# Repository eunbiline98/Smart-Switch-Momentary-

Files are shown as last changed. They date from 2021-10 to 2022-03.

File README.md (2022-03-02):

# Smart Switch Momentary

DIY Smart Switch momentary 2 Gang and 2 Channel Relay SPDT

List Item

- Esp8266 (Wemos D1 Mini) / Chip SoC Esp8266
- Relay 5VDC SPDT Songle (Max Current 10A)
- Power Module Hi-Link 220VAC to 5VDC
- Resistor 1k, 10K (SMD 0805)
- Diode 1N4007 SMD
- Transistor 2n2222a
- Terminal Screw 6 Pin Hole
- Push Button (schneider momentary switch) Datasheet: https://download.schneider-electric.com/files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

# Schematic
schematic

# Layout 
### Top View 
top

### Bottom View
bottom

# Home Assistant

Under covers in HA, use this config

```
mqtt:
  broker: "Your IP Broker/server"
  port: Your port MQTT
  username: "Your username"
  password: Your password

switch:
  - platform: mqtt
    name: "General Lamp"
    state_topic: "switch/bedroom1/1/state"
    command_topic: "switch/1/command"
    payload_on: "1"
    payload_off: "0"

 switch:
  - platform: mqtt
    name: "Cove Lighting"
    state_topic: "switch/bedroom1/2/state"
    command_topic: "switch/2/command"
    payload_on: "1"
    payload_off: "0"
```



IMAGE ALT TEXT HERE (https://www.youtube.com/watch?v=DARuhkKLw8E")

# Reference

- WiFi Manager (https://github.com/tzapu/WiFiManager)
- MQTT (https://github.com/knolleary/pubsubclient)

# Update

- DIY_switch_3_gang_Ver_1_0 (Test Board Circuit)
- DIY_switch_3_gang_Ver_1_0_WM (Update Feature WifI Manager)
- DIY_switch_3_gang_Ver_1_1_WM (Update Last State Condition Dashboard Home Assistant)
- DIY_switch_3_gang_Ver_1_2_WM (Update Feature WiFi and Mqtt Config Manager)

# Dimension

- L = 69,84 mm
- W = 70,87 mm

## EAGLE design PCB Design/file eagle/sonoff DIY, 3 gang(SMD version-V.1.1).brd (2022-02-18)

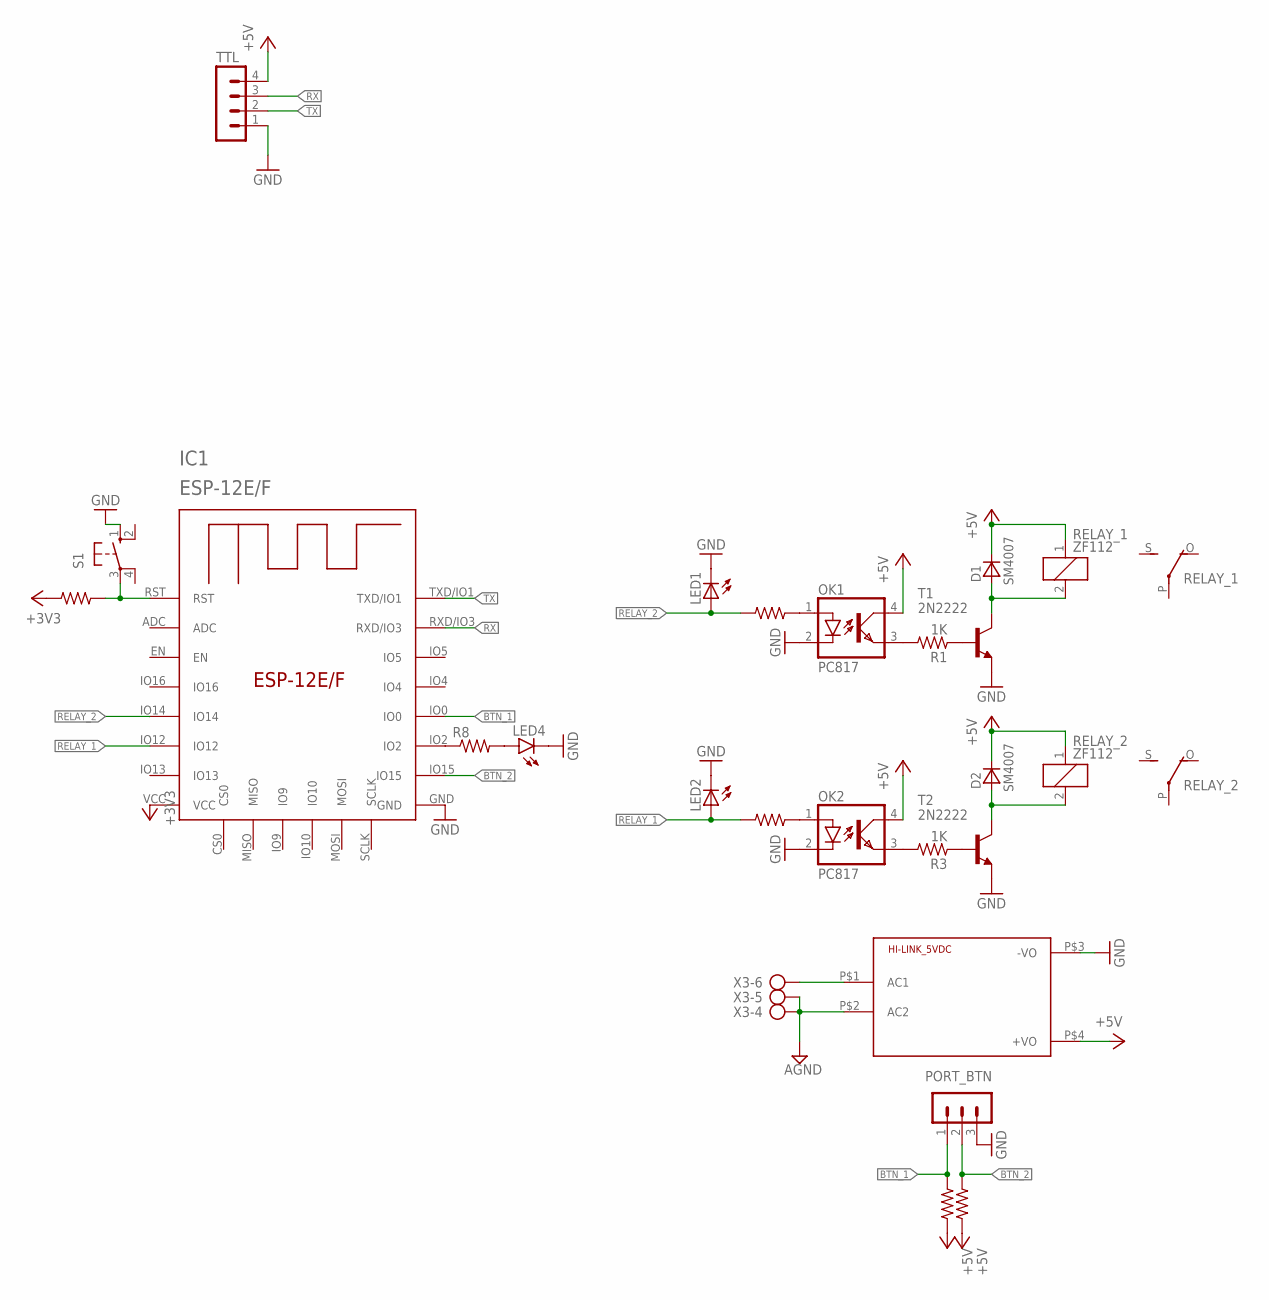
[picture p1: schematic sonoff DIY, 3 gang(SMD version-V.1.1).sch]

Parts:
D1, D2: SM4007; MELF-MLL41
HI-LINK_5VDC: HLK-PM013W; HLK-PM01
IC1: ESP-12E/F; ESP-12E
LED1, LED2, LED4: LED3MM
OK1, OK2: PC817; DIL04
PORT_BTN: MA03-1
R1, R2, R3, R4, R5, R6, R7: 1K; R0805
R8: R-US_0207/10; 0207/10
RELAY_1, RELAY_2: ZF112
S1: 10-XX; B3F-10XX
T1, T2: 2N2222; TO18
TTL: MA04-1
X3: SMKDSP_1,5/6

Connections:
+3V3: IC1.VCC, R7.2
+5V: D1.C, D2.C, HI-LINK_5VDC.P$4 (+VO), OK1.4 (COL), OK2.4 (COL), R5.2, R6.2, RELAY_1.1, RELAY_2.1, TTL.4
AGND: HI-LINK_5VDC.P$2 (AC2), X3.4, X3.5
BTN_1: IC1.IO0, PORT_BTN.1, R5.1
BTN_2: IC1.IO15, PORT_BTN.2, R6.1
GND: HI-LINK_5VDC.P$3 (-VO), IC1.GND, LED1.K (C), LED2.K (C), LED4.K (C), OK1.2 (C), OK2.2 (C), PORT_BTN.3, S1.1 (S), T1.1 (E), T2.1 (E), TTL.1
unnamed: OK1.1 (A), R2.1
unnamed: OK1.3 (EMIT), R1.2
unnamed: R1.1, T1.2 (B)
unnamed: D1.A, RELAY_1.2, T1.3 (C)
unnamed: OK2.1 (A), R4.1
unnamed: HI-LINK_5VDC.P$1 (AC1), X3.6
unnamed: OK2.3 (EMIT), R3.2
unnamed: R3.1, T2.2 (B)
unnamed: D2.A, RELAY_2.2, T2.3 (C)
unnamed: IC1.RST, R7.1, S1.3
unnamed: IC1.IO2, R8.1
unnamed: LED4.A, R8.2
RELAY_1: IC1.IO12, LED2.A, R4.2
RELAY_2: IC1.IO14, LED1.A, R2.2
RX: IC1.RXD/IO3, TTL.3
TX: IC1.TXD/IO1, TTL.2

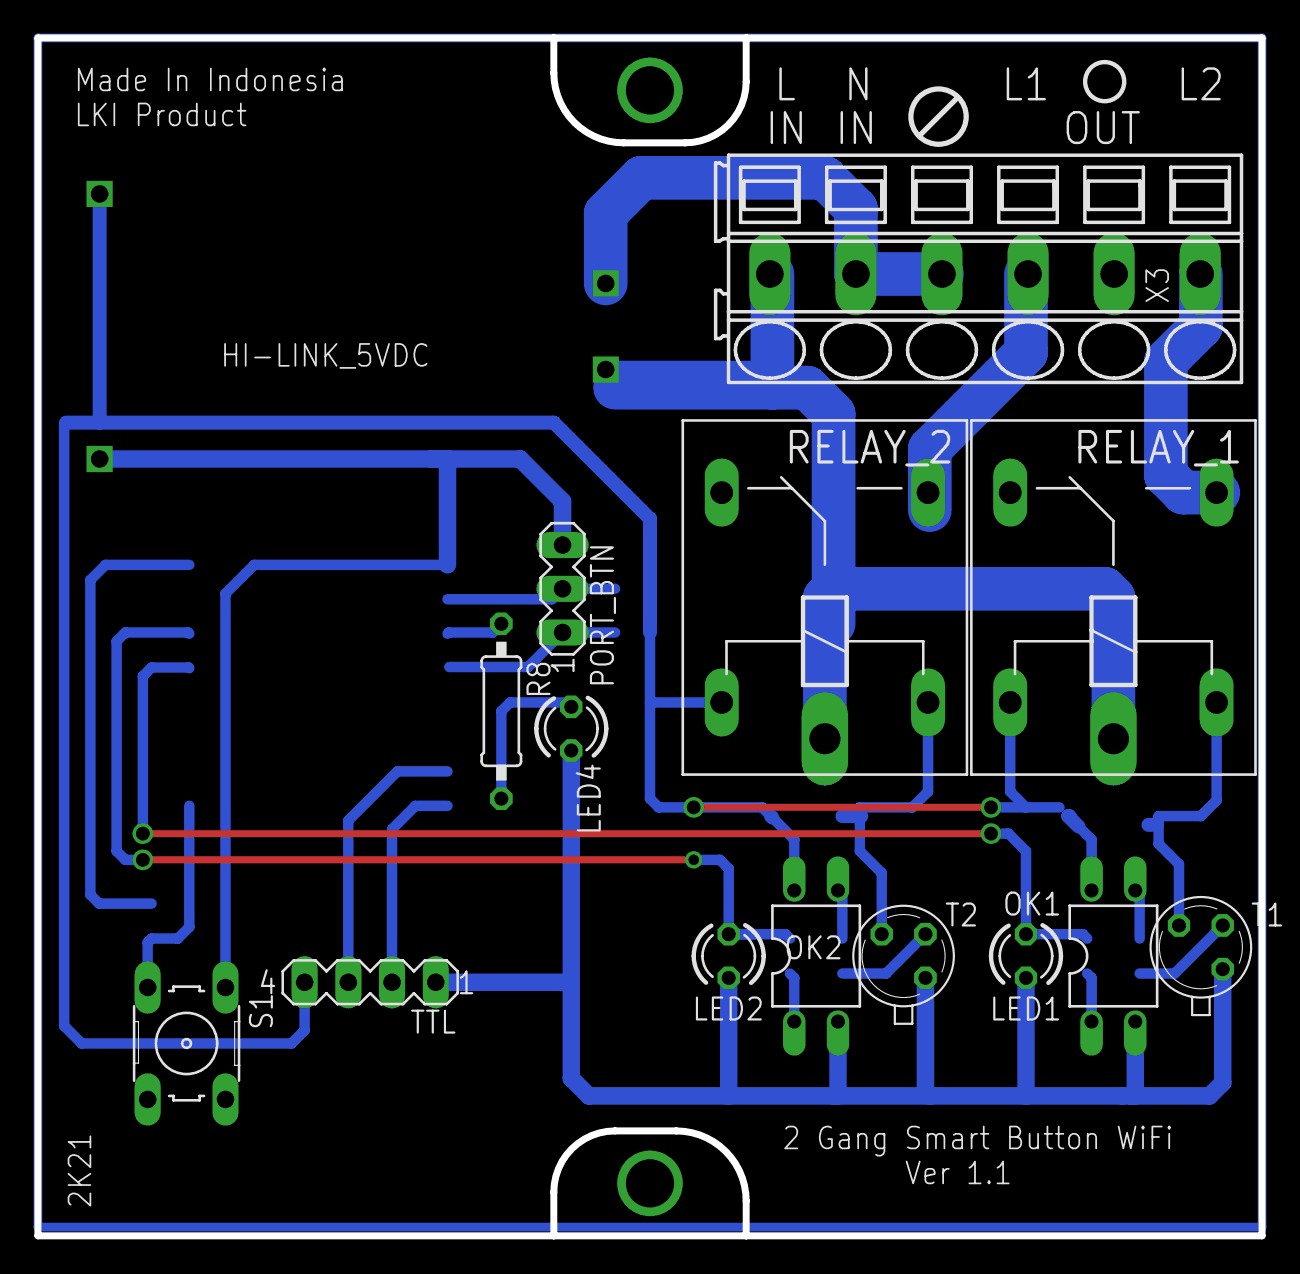
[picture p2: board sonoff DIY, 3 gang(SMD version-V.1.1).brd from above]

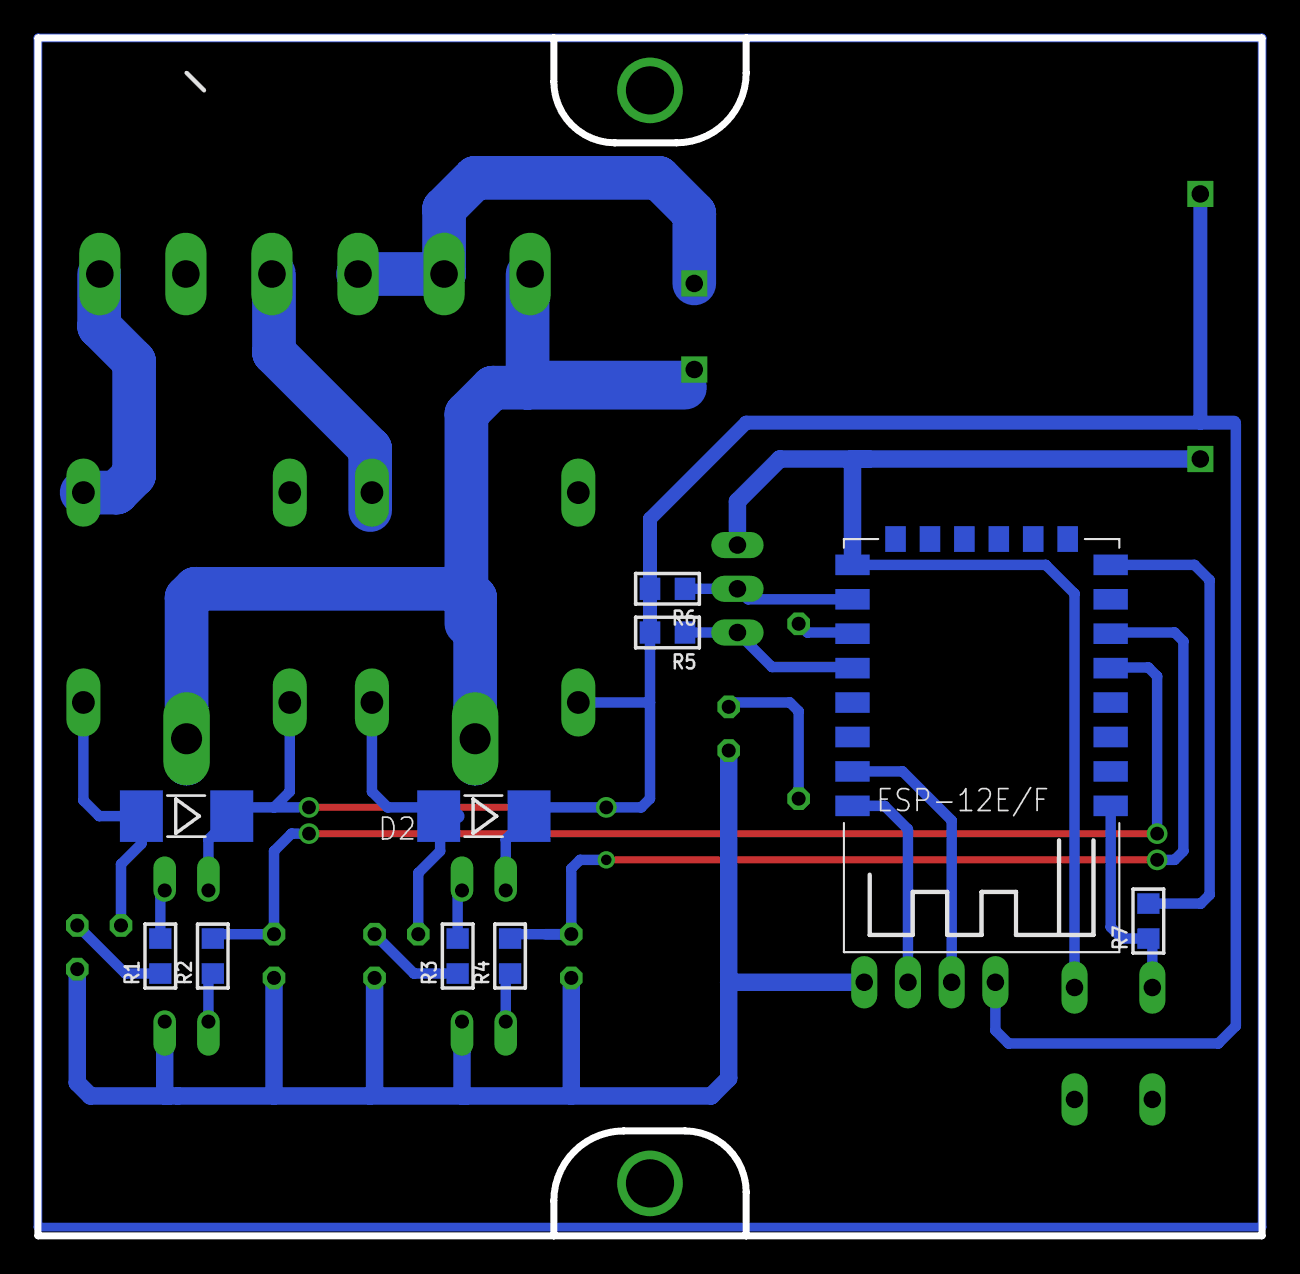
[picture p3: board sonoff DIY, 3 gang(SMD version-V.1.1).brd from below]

Board: 2 copper layers, 71.1 x 69.6 mm, 25 parts (10 on the bottom side), 22 nets.

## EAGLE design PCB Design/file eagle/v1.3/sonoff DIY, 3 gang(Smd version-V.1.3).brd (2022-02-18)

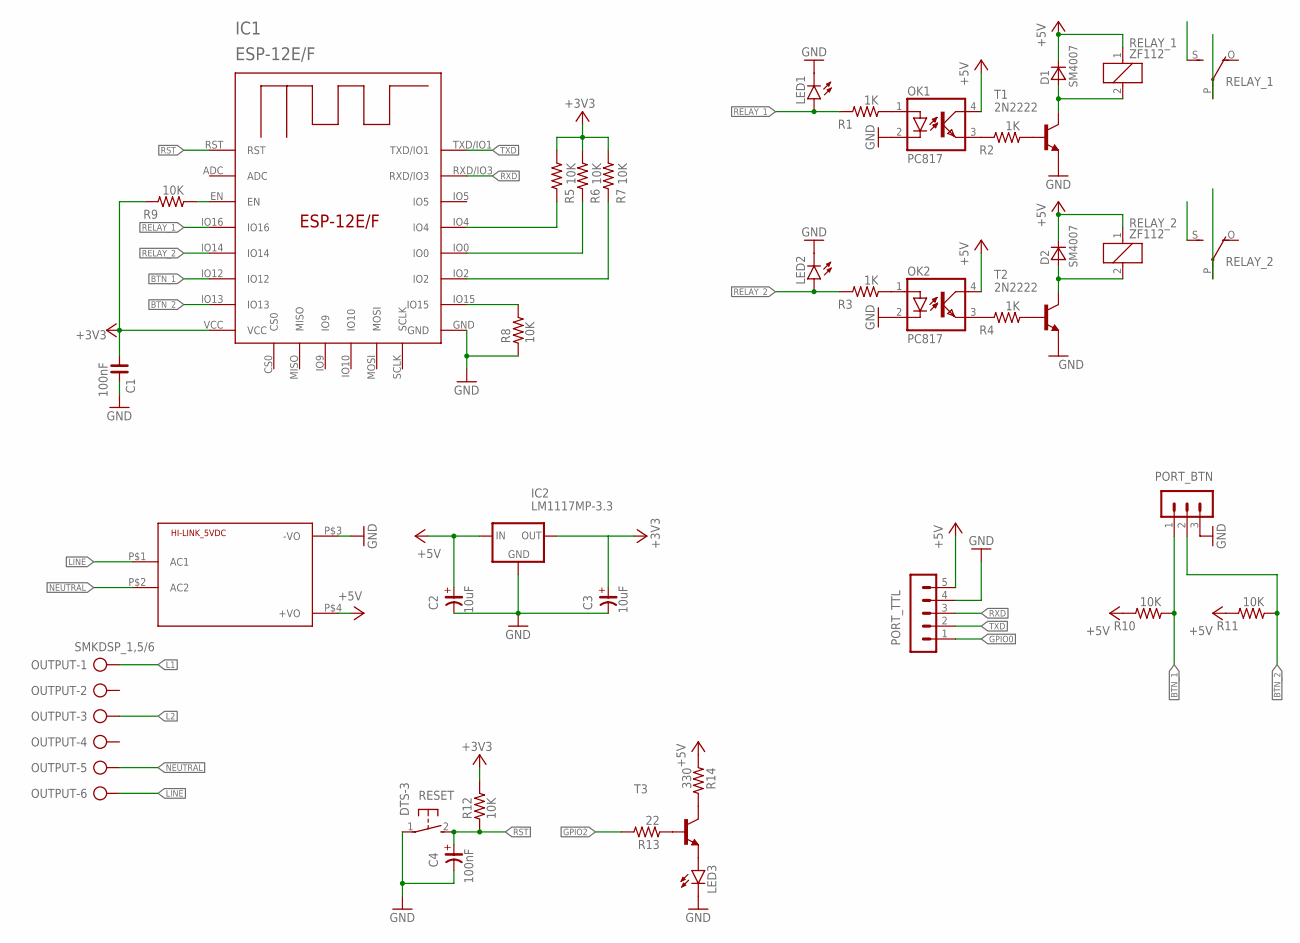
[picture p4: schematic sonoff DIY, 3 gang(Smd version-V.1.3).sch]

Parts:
C1: 100nF; C0805
C2, C3: 10uF; C3528/T
C4: 100nF; C3528/T
D1, D2: SM4007; MELF-MLL41
HI-LINK_5VDC: HLK-PM013W; HLK-PM01
IC1: ESP-12E/F; ESP-12E
IC2: LM1117MP-3.3; SOT223
LED1, LED2, LED3: LED3MM
OK1, OK2: PC817; DIL04
OUTPUT: SMKDSP_1,5/6
PORT_BTN: MA03-1
PORT_TTL: MA05-1
R1, R2, R3, R4: 1K; R0805
R5, R6, R7, R8, R9, R10, R11, R12: 10K; R0805
R13: 22; R0805
R14: 330; R0805
RELAY_1, RELAY_2: ZF112
RESET: DTS-3
T1, T2: 2N2222; TO18
T3: BC817-16LT1-NPN-SOT23-BEC; SOT23-BEC

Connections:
+3V3: C1.1, C3.+, IC1.VCC, IC2.2 (OUT), IC2.4 (OUT), R5.1, R6.1, R7.1, R9.2, R12.2
+5V: C2.+, D1.C, D2.C, HI-LINK_5VDC.P$4 (+VO), IC2.3 (IN), OK1.4 (COL), OK2.4 (COL), PORT_TTL.5, R10.2, R11.2, R14.1, RELAY_1.1, RELAY_2.1
BTN_1: IC1.IO12, PORT_BTN.1, R10.1
BTN_2: IC1.IO13, PORT_BTN.2, R11.1
GND: C1.2, C2.-, C3.-, C4.-, HI-LINK_5VDC.P$3 (-VO), IC1.GND, IC2.1 (GND), LED1.K (C), LED2.K (C), LED3.K (C), OK1.2 (C), OK2.2 (C), PORT_BTN.3, PORT_TTL.4, R8.1, RESET.1, T1.1 (E), T2.1 (E)
GPIO0: IC1.IO0, PORT_TTL.1, R6.2
GPIO2: IC1.IO2, R7.2, R13.2
L1: OUTPUT.1, RELAY_1.S
L2: OUTPUT.3, RELAY_2.S
LINE: HI-LINK_5VDC.P$1 (AC1), OUTPUT.6, RELAY_1.P, RELAY_2.P
unnamed: OK1.3 (EMIT), R2.2
unnamed: R2.1, T1.2 (B)
unnamed: OK2.1 (A), R3.1
unnamed: D1.A, RELAY_1.2, T1.3 (C)
unnamed: OK2.3 (EMIT), R4.2
unnamed: R4.1, T2.2 (B)
unnamed: OK1.1 (A), R1.1
unnamed: IC1.IO4, R5.2
unnamed: D2.A, RELAY_2.2, T2.3 (C)
unnamed: LED3.A, T3.E
unnamed: IC1.IO15, R8.2
unnamed: R13.1, T3.B
unnamed: IC1.EN, R9.1
unnamed: R14.2, T3.C
NEUTRAL: HI-LINK_5VDC.P$2 (AC2), OUTPUT.5
RELAY_1: IC1.IO16, LED1.A, R1.2
RELAY_2: IC1.IO14, LED2.A, R3.2
RST: C4.+, IC1.RST, R12.1, RESET.2
RXD: IC1.RXD/IO3, PORT_TTL.3
TXD: IC1.TXD/IO1, PORT_TTL.2

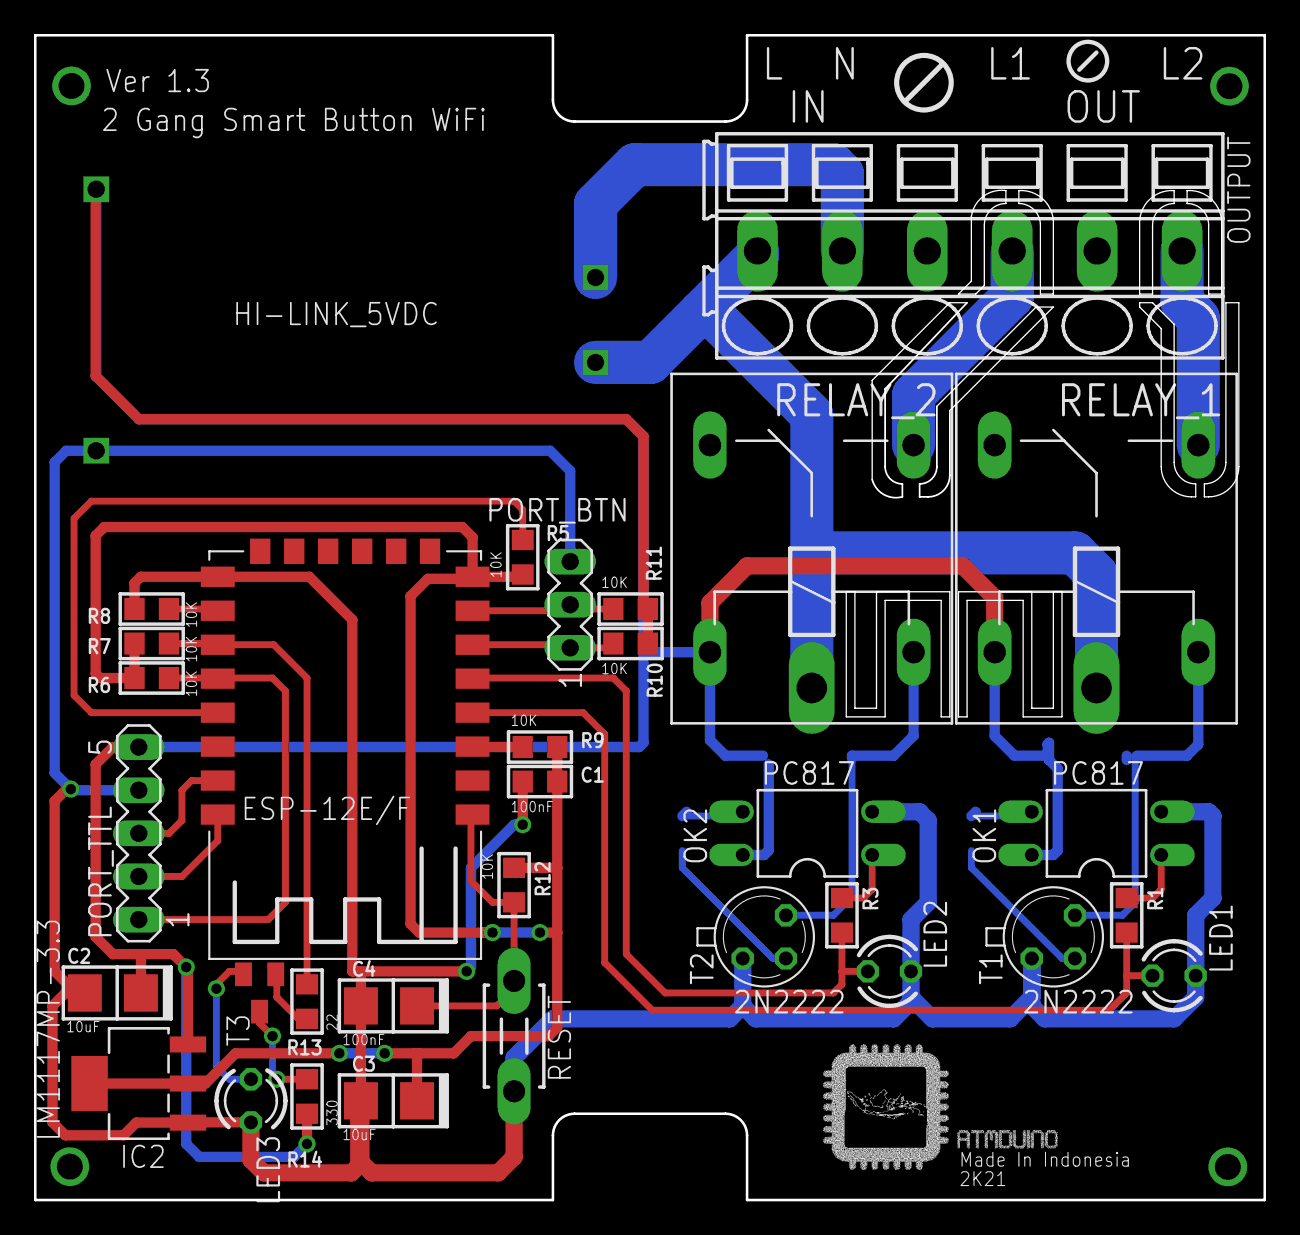
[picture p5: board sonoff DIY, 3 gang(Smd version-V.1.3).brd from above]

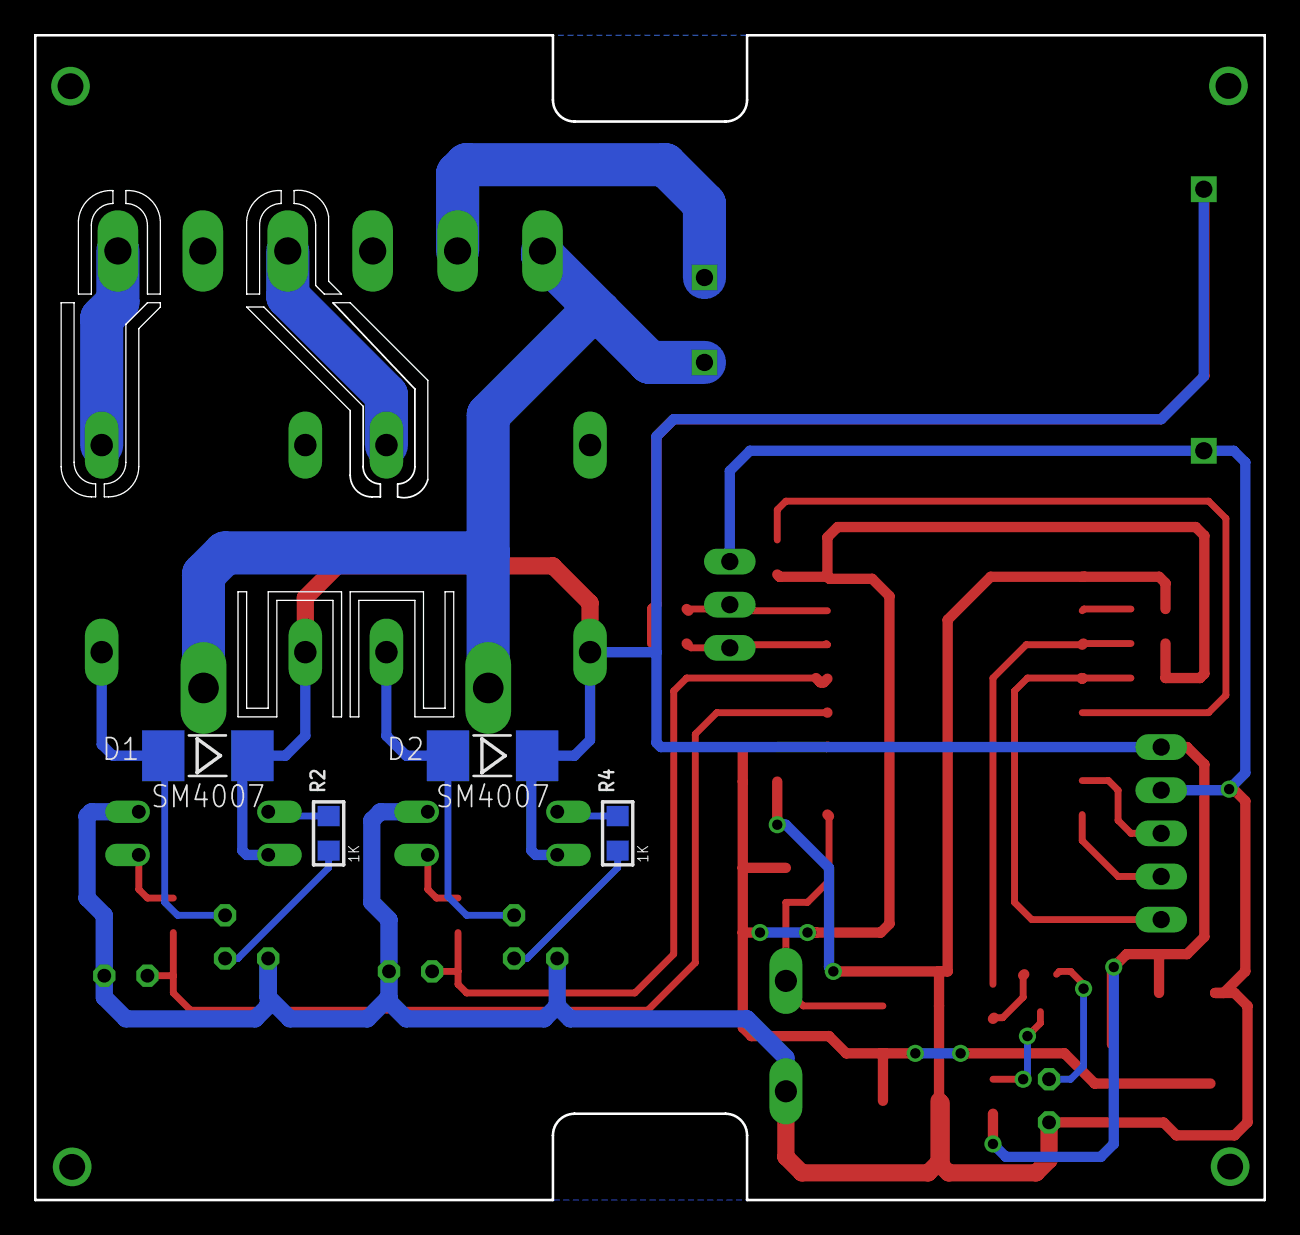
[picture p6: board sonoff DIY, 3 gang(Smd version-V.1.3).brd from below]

Board: 2 copper layers, 72.4 x 68.6 mm, 37 parts (4 on the bottom side), 30 nets.

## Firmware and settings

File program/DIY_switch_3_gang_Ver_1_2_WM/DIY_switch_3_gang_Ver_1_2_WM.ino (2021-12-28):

#include <ESP8266WiFi.h>
#include <PubSubClient.h>
#include <WiFiManager.h>
#include <Ticker.h>
#include <FS.h>
#include <ArduinoJson.h>
#include <DNSServer.h>

// set at text box mqtt config manager
#define MQTT_SERVER "Input Your Broker"
#define MQTT_PORT "Input Your Port"
#define MQTT_USERNAME "Input Your Username"
#define MQTT_PASSWORD "Input Your Password"

const char *MQTT_TOPIC1 = "switch/bedroom1/1/state";
const char *MQTT_TOPIC2 = "switch/bedroom1/2/state";
const char *MQTT_STATUS = "switch/bedroom1/status";
const char *SWITCH1 = "switch/1/command";
const char *SWITCH2 = "switch/2/command";

const char *MQTT_CLIENT_ID = "swtich_ID_1";

// Pin Setup
#define relay_1 14
#define relay_2 12
#define btn_1 5
#define btn_2 4

int flag1 = 0;
int flag2 = 0;
int state = 0;
int wifi_trigger = 0;

int lastMilis = 0;
unsigned long nowMillis = millis();
bool shouldSaveConfig = false;

WiFiClient espClient;
PubSubClient client(espClient);
Ticker ticker;

// callback notifying us of the need to save config
void saveConfigCallback()
{
  Serial.println("Should save config");
  shouldSaveConfig = true;
}

void tick()
{
  // toggle state
  digitalWrite(2, !digitalRead(2)); // set pin GPIO2 Led Wemos On-board
}

void configModeCallback(WiFiManager *myWiFiManager)
{
  Serial.println("Entered config mode");
  Serial.println(WiFi.softAPIP());
  // if you used auto generated SSID, print it
  Serial.println(myWiFiManager->getConfigPortalSSID());
  // entered config mode, make led toggle faster
  ticker.attach(0.2, tick);
}

void setup_wifi()
{
  WiFi.mode(WIFI_STA);
  pinMode(2, OUTPUT);
  ticker.attach(0.6, tick);

  // clean FS for testing
  //   SPIFFS.format();

  // read configuration from FS json
  Serial.println("mounting FS...");

  if (SPIFFS.begin())
  {
    Serial.println("mounted file system");
    if (SPIFFS.exists("/config.json"))
    {
      // file exists, reading and loading
      Serial.println("reading config file");
      File configFile = SPIFFS.open("/config.json", "r");
      if (configFile)
      {
        Serial.println("opened config file");
        size_t size = configFile.size();
        // Allocate a buffer to store contents of the file.
        std::unique_ptr<char[]> buf(new char[size]);

        configFile.readBytes(buf.get(), size);
        DynamicJsonBuffer jsonBuffer;
        JsonObject &json = jsonBuffer.parseObject(buf.get());
        json.printTo(Serial);
        if (json.success())
        {
          Serial.println("\nparsed json");
          strcpy(MQTT_SERVER, json["mqtt_server"]);
          strcpy(MQTT_PORT, json["mqtt_port"]);
          strcpy(MQTT_USERNAME, json["mqtt_username"]);
          strcpy(MQTT_PASSWORD, json["mqtt_password"]);
        }
        else
        {

          Serial.println("failed to load json config");
        }
      }
    }
  }
  else
  {
    Serial.println("failed to mount FS");
  }

  WiFiManagerParameter custom_mqtt_server("server", "mqtt server", MQTT_SERVER, 40);
  WiFiManagerParameter custom_mqtt_port("port", "mqtt port", MQTT_PORT, 40);
  WiFiManagerParameter custom_mqtt_user("user", "mqtt user", MQTT_USERNAME, 40);
  WiFiManagerParameter custom_mqtt_pass("pass", "mqtt pass", MQTT_PASSWORD, 40);

  WiFiManager wm;
  wm.setAPCallback(configModeCallback);

  wm.addParameter(&custom_mqtt_server);
  wm.addParameter(&custom_mqtt_port);
  wm.addParameter(&custom_mqtt_user);
  wm.addParameter(&custom_mqtt_pass);

  if (!wm.autoConnect() || digitalRead(btn_2) == LOW)
  {
    Serial.println("failed to connect");
    wm.resetSettings();
    ESP.restart();
    delay(1000);
  }

  Serial.println("connected...");

  strcpy(MQTT_SERVER, custom_mqtt_server.getValue());
  strcpy(MQTT_PORT, custom_mqtt_port.getValue());
  strcpy(MQTT_USERNAME, custom_mqtt_user.getValue());
  strcpy(MQTT_PASSWORD, custom_mqtt_pass.getValue());

  // save the custom parameters to FS
  if (shouldSaveConfig)
  {
    Serial.println("saving config");
    DynamicJsonBuffer jsonBuffer;
    JsonObject &json = jsonBuffer.createObject();
    json["mqtt_server"] = MQTT_SERVER;
    json["mqtt_port"] = MQTT_PORT;
    json["mqtt_user"] = MQTT_USERNAME;
    json["mqtt_pass"] = MQTT_PASSWORD;

    File configFile = SPIFFS.open("/config.json", "w");
    if (!configFile)
    {
      Serial.println("failed to open config file for writing");
    }

    json.printTo(Serial);
    json.printTo(configFile);
    configFile.close();
    // end save
  }

  ticker.detach();
  digitalWrite(2, LOW);
}

void button_func()
{
  // button1
  int stateBtn_1 = digitalRead(btn_1);
  if (!stateBtn_1 && !flag1)
  {
    if (state == 0)
    {
      client.publish(MQTT_TOPIC1, "1");
      digitalWrite(relay_1, HIGH);
      state = 1;
    }
    else
    {
      client.publish(MQTT_TOPIC1, "0");
      digitalWrite(relay_1, LOW);
      state = 0;
    }
    flag1 = 1;
  }
  else if (stateBtn_1 && flag1)
  {
    flag1 = 0;
  }
  // button2
  int stateBtn_2 = digitalRead(btn_2);
  if (!stateBtn_2 && !flag2)
  {
    if (state == 0)
    {
      client.publish(MQTT_TOPIC2, "1");
      digitalWrite(relay_2, HIGH);
      state = 1;
    }
    else
    {
      client.publish(MQTT_TOPIC2, "0");
      digitalWrite(relay_2, LOW);
      state = 0;
    }
    flag2 = 1;
  }
  else if (stateBtn_2 && flag2)
  {
    flag2 = 0;
  }
  delay(100);
}

void callback(char *topic, byte *message, unsigned int length)
{
  Serial.print("Message arrived in topic: ");
  Serial.println(topic);
  Serial.print("Message:");
  String messageTemp;

  for (int i = 0; i < length; i++)
  {
    Serial.print((char)message[i]);
    Serial.println();
    if ((char)message[i] != '"')
      messageTemp += (char)message[i];
  }

  if (String(topic) == SWITCH1)
  {
    if (messageTemp == "1")
    {
      digitalWrite(relay_1, HIGH);
      client.publish(MQTT_TOPIC1, "1");
    }
    else if (messageTemp == "0")
    {
      digitalWrite(relay_1, LOW);
      client.publish(MQTT_TOPIC1, "0");
    }
  }

  if (String(topic) == SWITCH2)
  {
    if (messageTemp == "1")
    {
      digitalWrite(relay_2, HIGH);
      client.publish(MQTT_TOPIC2, "1");
    }
    else if (messageTemp == "0")
    {
      digitalWrite(relay_2, LOW);
      client.publish(MQTT_TOPIC2, "0");
    }
  }
}

void reconnect()
{
  // Loop until we're reconnected
  while (!client.connected())
  {
    Serial.print("Attempting MQTT connection...");
    // Attempt to connect
    if (client.connect(MQTT_CLIENT_ID, MQTT_USERNAME, MQTT_PASSWORD, MQTT_STATUS, 1, 1, "Offline"))
    {
      Serial.println("connected");
      // subscribe
      client.subscribe(SWITCH1);
      client.subscribe(SWITCH2);
      client.publish(MQTT_STATUS, "Online", true);
    }
    else
    {
      Serial.print("failed, rc=");
      Serial.print(client.state());
      Serial.println(" try again in 5 seconds");
      // Wait 5 seconds before retrying
      delay(5000);
    }
  }
}

void setup()
{
  // Serial port for debugging purposes
  Serial.begin(115200);
  setup_wifi();

  // MQTT Server Setup
  client.setServer(MQTT_SERVER, atoi(MQTT_PORT));
  client.setCallback(callback);

  pinMode(2, OUTPUT); // WiFi Indicator
  pinMode(relay_1, OUTPUT);
  pinMode(relay_2, OUTPUT);

  pinMode(btn_1, INPUT);
  pinMode(btn_2, INPUT);
}

void loop()
{
  if (!client.connected())
  {
    reconnect();
  }

  button_func();
  client.loop();
}

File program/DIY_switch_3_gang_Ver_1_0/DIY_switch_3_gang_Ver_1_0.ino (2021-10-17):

#include <ESP8266WiFi.h>
#include <PubSubClient.h>

const char* ssid = ".............";
const char* password = "............";
const char* MQTT_SERVER = "192.168.x.xxx";
const char* MQTT_TOPIC = "switch/bedroom/1";

const char* MQTT_CLIENT_ID = "switch_bedroom1";
const char* MQTT_USERNAME = "..........";
const char* MQTT_PASSWORD = "..........";

WiFiClient espClient;
PubSubClient client(espClient);

// Pin Setup
#define relay_1 14
#define relay_2 12
#define btn_1 5
#define btn_2 4
int flag1 = 0;
int flag2 = 0;
int state = 0;

void setup_wifi() {
  // Connect to Wifi Network
  pinMode(2, OUTPUT); //WiFi Indicator
  Serial.println();
  Serial.print("Connecting to ");
  Serial.println(ssid);

  WiFi.begin(ssid, password);

  while (WiFi.status() != WL_CONNECTED)
  {
    digitalWrite(2, HIGH);
    delay(80);
    digitalWrite(2, LOW);
    delay(80);
  }

  Serial.println("");
  Serial.println("WiFi connected");
  Serial.println("IP address: ");
  Serial.println(WiFi.localIP());
}

void button_func() {
  // button1
  int stateBtn_1 = digitalRead(btn_1);
  if (!stateBtn_1 && !flag1) {
    if (state == 0) {
      client.publish(MQTT_TOPIC,"1");
      state = 1;
    } else {
      client.publish(MQTT_TOPIC,"2");
      state = 0;
    }
    flag1 = 1;
  } else if (stateBtn_1 && flag1) {
    flag1 = 0;
  }
  // button2
  int stateBtn_2 = digitalRead(btn_2);
  if (!stateBtn_2 && !flag2) {
    if (state == 0) {
      client.publish(MQTT_TOPIC,"3");
      state = 1;
    } else {
      client.publish(MQTT_TOPIC,"4");
      state = 0;
    }
    flag2 = 1;
  } else if (stateBtn_2 && flag2) {
    flag2 = 0;
  }
  delay(100);
}

void callback(char* topic, byte* message, unsigned int length)
{
  Serial.print("Message arrived in topic: ");
  Serial.println(topic);
  Serial.print("Message:");
  String messageTemp;

  if (String(topic) != MQTT_TOPIC) {
    return;
  }

  for (int i = 0; i < length; i++) {
    Serial.print((char)message[i]);
    if ((char)message[i] != '"')
      messageTemp += (char)message[i];
  }
  // Changes the output state according to the message
  Serial.println("");
  Serial.print("Changing output to ");
  //  Serial.println(messageTemp);
  if (messageTemp == "1") {
    Serial.println("Relay_1On");
    digitalWrite(relay_1, HIGH);
  }
  if (messageTemp == "2") {
    Serial.println("Relay_1Off");
    digitalWrite(relay_1, LOW);
  }
  if (messageTemp == "3") {
    Serial.println("Relay_2On");
    digitalWrite(relay_2, HIGH);
  }
  if (messageTemp == "4") {
    Serial.println("Relay_2Off");
    digitalWrite(relay_2, LOW);
  }
}

void reconnect() {
  // Loop until we're reconnected
  while (!client.connected()) {
    Serial.print("Attempting MQTT connection...");
    // Attempt to connect
    if (client.connect(MQTT_CLIENT_ID, MQTT_USERNAME, MQTT_PASSWORD )) {
      Serial.println("connected");
      //subscribe
      client.subscribe(MQTT_TOPIC);
    } else {
      Serial.print("failed, rc=");
      Serial.print(client.state());
      Serial.println(" try again in 5 seconds");
      // Wait 5 seconds before retrying
      delay(5000);
    }
  }
}

void setup() {
  // Serial port for debugging purposes
  Serial.begin(115200);
  setup_wifi();

  // MQTT Server Setup
  client.setServer(MQTT_SERVER, 1883);
  client.setCallback(callback);

  pinMode(2, OUTPUT);//WiFi Indicator
  pinMode(relay_1, OUTPUT);
  pinMode(relay_2, OUTPUT);

  pinMode(btn_1, INPUT);
  pinMode(btn_2, INPUT);
}

void loop() {
  if (!client.connected()) {
    reconnect();
  }
  button_func();
  client.loop();
}

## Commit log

2021-10-10 Intial Commit
    [sonoff DIY, 3 gang(Dip version-V.1.1).brd, sonoff DIY, 3 gang(Dip version-V.1.1).sch]
2021-11-11 Udate fix mqtt port config
    [DIY_switch_3_gang_Ver_1_2_WM.ino]
2022-01-22 Adding smd version
    [sonoff DIY, 3 gang(SMD version-V.1.1).brd, sonoff DIY, 3 gang(SMD version-V.1.1).sch]
2022-02-18 Adding Design PCB V1.3
    [sonoff DIY, 3 gang(Smd version-V.1.3).brd, sonoff DIY, 3 gang(Smd version-V.1.3).sch]
2022-02-18 Adding Design PCB
    [sonoff DIY, 3 gang(Dip version-V.1.1 new).sch, sonoff DIY, 3 gang(Dip version-V.1.1).brd, sonoff DIY, 3 gang(Dip version-V.1.1).sch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]

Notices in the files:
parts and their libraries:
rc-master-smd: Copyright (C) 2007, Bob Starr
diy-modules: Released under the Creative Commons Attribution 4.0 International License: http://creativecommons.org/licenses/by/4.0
